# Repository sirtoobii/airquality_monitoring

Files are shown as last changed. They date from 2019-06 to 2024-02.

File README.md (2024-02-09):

### Air quality monitoring
This projects aims to create an air quality monitoring setup with inexpensive components. Initially
setup with an Arduino nano but later ported to a Raspberry PI.

The data is collected using the following sensors:  
- BMP180 (Air pressure, Temperature)
- MH-Z19B (Co2 concentration)
- SMT20 (Humidity, Temperature)
To interface with the sensors, either an Arduino or Raspberry PI computer can be used

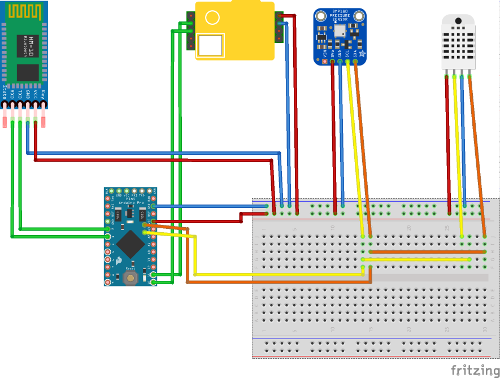
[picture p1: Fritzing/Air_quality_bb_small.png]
Ardunio board


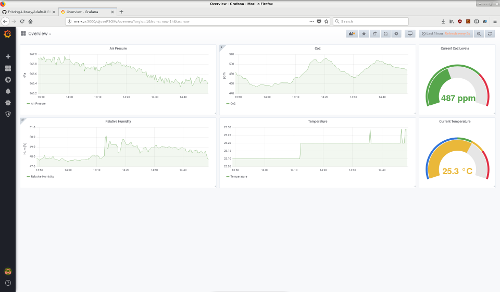
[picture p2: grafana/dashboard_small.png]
Grafana Dashboard


### Project Structure

| Folder | Description | Remarks |
|---|---|---|
| `Fritzing` | The Fritzing projcet | Get fritzing here:[https://fritzing.org/home/](https://fritzing.org) |
| `additional` | Datasets for the sensors | |
| `arduino` | Ardunio libraries and source code. | This is a platfrom-io project. More info [https://platformio.org/](here) |
| `grafana` | Just the exported `grafana` dashboard | |
| `pi` | This project implemented on a Raspberry PI | |
| `python` | Python files: Write data values to the influx db (`data_logger.py`) and scan for new advertisement packets (`scanner.py`) |  There is `requirements.txt` file present, which use to install all required packages: ```pip install -i requirements.txt``` |

### Technology Stack
- Data is stored in a Influx-DB
- A Grafana-Dashboard is used to display the measured values
- Scripting language at the receiver-side is Python `3.6`
- (Arduino) The data is transmitted using iBeacon `UUID-String` (yes this is a hack see more info below)

### Data transmission (Arduino)
As mentioned above the collected data is transmitted using Bluetooth Low Energy to
the receiver. Generally speaking, the data is transmitted using the advertisement
data:
```
Index         :        7   11 13   15     19 21   23 25                  39
                       |    |  |    |      |  |    |  |                   |
Example string: 4c000215 0190 1b   27   03c9 27   a0 a0   0000000 000000 2d       ffe0ffe1 c5
Labels        : Ibeacon  co2  temp.temp pres.pres hum.hum ------- ------ checksum other_stuff
```
However, since the HM-10 does not support changing the advertisement data
directly, I had to _abuse_ the iBeacon mode where you can change 32 Bytes of the `UUID-String`. To make things worse (more interesting!), the BLE-Module only allows you to
change 8 Bytes of the `UUID-String` at once. For example the `AT` command for the first 8 Bytes:
```
AT+IBE0AABBCCDD # As a side-note: all Hex-Characters have to be upper-case
```
And you guessed it, you can't control **when** an advertisement package is sent.
This the reason the checksum is needed :)

### Future work, remarks and problems
- Currently only one temperature value is evaluated. However, all sensors measure
temperature, therefore we could compare them and even create some sort of a _confidence-interval_
- If you power on the whole circuit, the first _valid_ (according to the checksum) transmitted value of the co2-sensor is sometimes way off (in the 5-6k area)
- Don't buy the components on aliexpres or similar. I've wasted (too) many hours figuring out that for example the HM-10 Module was a clone of a _clone_ of the original.
- Feedback, ideas and PR's welcome :)

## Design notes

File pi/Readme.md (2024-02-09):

# Raspberry PI variant

The same project but implemented on a Raspberry PI instead of an Arduino. 

## Raspberry PI setup

- Enable I2C: `raspi-config->Interface Options->I2C`
- Enable Serial port: `raspi-config->Interface Options->Serial Port` (login shell: no) (serial port hardware: yes)
- Wiring: Check comments in each sensor implementation
- 
Setup Python3 environment (inside `/pi` directory)

```shell
# Setup venv
python3 -m venv venv

# activate venv
source venv/bin/activate

# install requirements
pip install -r requirements.txt

# copy and edit .env file according your local environment
cp .env.dist .env

# add your user to "dialout" group to access the serial and i2c interface as non root user
usermod -aG dialout <user_name>
```
The corresponding systemd service (to be placed in `/usr/lib/systemd/system/raspi-airquality.service`)
```text
[Unit]
Description=Air-quality Monitoring
After=network.target
Wants=network-online.target

[Service]
Restart=always
Type=simple
Type=simple
ExecStart=/home/<user_name>/airquality_monitoring/pi/venv/bin/python3 /home/<user_name>/airquality_monitoring/pi/app/main.py
User=<user_name>
Group=<user_group>

[Install]
WantedBy=multi-user.target 
```

You probably also want to enable the service on boot: `systemctl enable raspi-airquality.service`

## Influx and Grafana

I highly recommend using this docker-compose setup: [https://github.com/sirtoobii/docker-compose-influxdb-grafana](https://github.com/sirtoobii/docker-compose-influxdb-grafana). The [included grafana
dashboard config](../grafana/Dashboard_config_influx_2_0.json) should work right away with this setup.

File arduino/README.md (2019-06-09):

### arduino_airquality
This project is work in progress!

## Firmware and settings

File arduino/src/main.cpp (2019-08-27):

#include <Wire.h>
#include <Adafruit_Sensor.h>
#include <Adafruit_BMP085_U.h>
#include <SoftwareSerial.h>
#include <DFRobot_SHT20.h>

#define unsigned char byte
#define CLOCK 20000 //Internal clock rate in milliseconds

/**
 * Common pitfalls:
 * - Allways clear serial buffers!
 * - When defining multiple SoftwareSerial objects make sure to call serial_object.listen() before interacting!
 */

SoftwareSerial SerialBLE(2, 3);  // BLE
SoftwareSerial SerialCO2(10,11);  // CO2
Adafruit_BMP085_Unified bmp = Adafruit_BMP085_Unified(10085); //Temperature & Presure
DFRobot_SHT20 sht20; //Humitity



byte READ_CO2[]={0xff,0x01,0x86,0x00,0x00,0x00,0x00,0x00,0x79};  //Befehl zum Auslesen der CO2 Konzentration

static char globalErrorState = 0x0;
const static char HEX_C[17]="0123456789ABCDEF";

/*
 * Possibile Error states
 * 0x0: No error
 * 0x1: Error at init BMP085
 * 0x2: Error at init SHT20
 * 0x3: Error reading sensor BMP085
 * 0x5: Error converting the data
 */
void indicateError(bool blocking=false){
  if (globalErrorState != 0x0) {
    while(true){
    for (int i=0; i<globalErrorState; i++){
        digitalWrite(LED_BUILTIN, HIGH);
        delay(100);
        digitalWrite(LED_BUILTIN, LOW);
        delay(100);
      }
      if (!blocking) {
        break;
      }
      delay(1000);
    }
    }
}
/**
 * Takes a char array a fills it with a given character
 **/
void fillWithChar(char data[], char character, int data_size){
  for (int i = 0; i < data_size; i++){
    data[i] = character;
  }
}

/**
 * Just writes an input char array to the BLE module. Also prints the response
 * to UART.
 **/
void writeToBle(const char * data){
  SerialBLE.listen();
  while (SerialBLE.available() >0) {     //Hier wird der Buffer der Seriellen Schnittstelle gelehrt
    SerialBLE.read();
  }
  Serial.println(data);
  SerialBLE.write(data);
  Serial.println(SerialBLE.readString());
}

/**
 * Converts an integer to its HEX representation and packs it into an char
 * array of a given length. The unused space in the array is padded with '0'.
 *
 **/
void packIntoHexChar(char data[], int buf_size, int value){
  static char hb = 0x0;
  static char lb = 0x0;
  static char int_chars[5] = "0000";
  //Fill with zero characters
  for (int i = 0; i<buf_size -1; i++){
    data[i] = '0';
  }
  //Convert value to hex
  hb = highByte(value);
  lb = lowByte(value);
  int_chars[0] = HEX_C[hb>>4 & 0x0F];
  int_chars[1] = HEX_C[hb & 0x0F];
  int_chars[2]=  HEX_C[lb>>4 & 0x0F];
  int_chars[3] = HEX_C[lb & 0x0F];
  //set value
  for (int i = buf_size -2; i >= 0; i--){
    if (buf_size -i <=5 ){
      data[i] = int_chars[(i+1) - (buf_size - 4)];
    }
  }
}
/**
 * Implemention of the "Fletcher's Checksum". To fit the result into two
 * HEX character we READ_CO2pute the modulo 16 of each value.
 **/
int sum1 = 0;
int sum2 = 0;
void computeChecksum(char input[], int input_size, char output[]){
  sum1 = 0;
  sum2 = 0;
  for (int i = 0; i < input_size; i++) {
    sum1 = (sum1 + input[i]) % 255;
    sum2 = (sum2 + sum1) % 255;
  }

output[0] = HEX_C[lowByte(sum1 % 16) & 0x0F];
output[1] = HEX_C[lowByte(sum2 % 16) & 0x0F];
}

/**
 * Takes an float value and converts it to a hex representation:
 * 16.16 => 000F000F (if the size is set to 5 (4))
 **/
void float2Hex(float value, double precision, char whole[], int whole_size, char remainder[], int remainder_size){
  static int v_whole = 0;
  static int v_remainder = 0;
  v_whole = value;
  v_remainder = (value - v_whole) * (int) pow(10, precision);
  packIntoHexChar(whole, whole_size, v_whole);
  packIntoHexChar(remainder, remainder_size, v_remainder);
}

/**
 * Takes an char array with a maximum length of 32 and distributes its contents
 * over the UUID field of the BLE module.
 */



void writeToUUID(char data[], int data_size){
  static char _data[9] = "00000000";
  static char _toSend[17];
  static char _READ_CO2mand[8];
  static char _checksum[3] = "00";
  static int array_pointer = 0;
  static int n_registers = 0;
  static int tail = 0;
  //Determine how many registers we need
  n_registers = data_size / 8;
  tail = data_size % 8;
  //Set checksum
  computeChecksum(data, data_size, _checksum);
  if (data_size > 30) {
    Serial.println("Too much data for the uuid field. 30 Bytes max! (last two are the checksum)");
    return;
  }
  //Easy base case
  if (n_registers == 0 && tail > 0){
    fillWithChar(_data, '0', 8);
    for (int i = 0; i < 8; i++){
      _data[i] = data[i];
    }
    strcpy(_toSend, "AT+IBE0");
    strcat(_toSend, _data);
    writeToBle(_toSend);
    return;
  }
  array_pointer = 0;
  //Process all except tail
  for (int i = 0; i< n_registers; i++){
    fillWithChar(_data, '0', 8);
    for (int j = array_pointer; j < 8 + array_pointer; j++){
      _data[j - array_pointer] = data[j];
    }
    array_pointer += 8;
    //Only send if this is not the last register
    if (i < 3){
      sprintf(_READ_CO2mand, "AT+IBE%d", i);
      strcpy(_toSend, _READ_CO2mand);
      strcat(_toSend, _data);
      writeToBle(_toSend);
    }
  }
  //Process tail
  if (array_pointer < data_size ) {
    fillWithChar(_data, '0', 8);
    for (int i = 0; i < data_size - array_pointer ; i++){
      _data[i] = data[i+array_pointer];
    }
    //Only send if this is not the last register
    if (n_registers < 3){
      sprintf(_READ_CO2mand, "AT+IBE%d", n_registers);
      strcpy(_toSend, _READ_CO2mand);
      strcat(_toSend, _data);
      writeToBle(_toSend);
    }
  }
  if (n_registers < 3){
    fillWithChar(_data, '0', 8);
  }
  //Write last register with checksum
  sprintf(_READ_CO2mand, "AT+IBE%d", 3);
  _data[6] = _checksum[0];
  _data[7] = _checksum[1];
  strcpy(_toSend, _READ_CO2mand);
  strcat(_toSend, _data);
  writeToBle(_toSend);
}

void setup(void)
{
  // Setupo led
  pinMode(LED_BUILTIN, OUTPUT);

  //Setup main serial
  Serial.begin(9600);
  Serial.println("Starting module");

  //Co2 Serial
  SerialCO2.begin(9600);  //Initialisierung der seriellen Schnittstelle für den ersten Sensor

  //Setup ble serial
  SerialBLE.begin(9600); // Sometimes the default baud rate is also 115200
  writeToBle("AT"); // Wake up
  writeToBle("AT+NAMEsensortag1"); //Set name
  writeToBle("AT+ADVIA"); // Set Advertising rate to  2000ms
  writeToBle("AT+ADTY3"); // Only advertise, no connect
  writeToBle("AT+IBEA1"); // Enable iBeacon mode
  //Reset id (we somehow can't set them to 0x0)
  writeToBle("AT+IBE000000001");
  writeToBle("AT+IBE100000001");
  writeToBle("AT+IBE200000001");
  writeToBle("AT+IBE300000001");
  writeToBle("AT+PWRM1"); // Disable sleep mode since I found no (working) way to enter operation mode again
  writeToBle("AT+RESET"); // Restart
  delay(1000);
  writeToBle("AT");

  Serial.println("Module is ready, initializing sensors...");
  //Indicate BLE ready
  digitalWrite(LED_BUILTIN, HIGH);
  delay(100);
  digitalWrite(LED_BUILTIN, LOW);
  delay(100);
  digitalWrite(LED_BUILTIN, HIGH);
  delay(100);
  digitalWrite(LED_BUILTIN, LOW);
  delay(100);

  // Setup BMP085
  if(!bmp.begin())
  {
    Serial.print("Ooops, no BMP085 detected");
    globalErrorState = 0x1;
    indicateError(true);
  }
  sht20.initSHT20();
  delay(100);

  Serial.println("Sensors initialized successfully");
}

void loop(void){
  static float temp = 0.0;
  static float presure = 0.0;
  static int co2_concentration = 0;
  static float humidity = 0.0;

  //co2 read buffer
  static byte buf_read_co2[9];

  //Send buffers
  static char buf_co2[5] = "0000";
  static char buf_temp_whole[3] = "00";
  static char buf_temp_remainder[3] = "00";
  static char buf_pres_whole[5] = "0000";
  static char buf_pres_remainder[3] = "00";
  static char buf_hum_whole[3] = "00";
  static char buf_hum_remainder[3] = "00";

  //Prepare whole buffer (only 19 since 25 - 6)
  // -6 Because we can remove the string termination characters
  static char buf_toSend[19];


  // Get a new sensor event
  sensors_event_t event;
  bmp.getEvent(&event);

  if (event.pressure)
  {
    presure = event.pressure;
    bmp.getTemperature(&temp);
    globalErrorState = 0x0;
  }
  else
  {
    globalErrorState = 0x3;
  }

  //Read co2 readings
  SerialCO2.listen();
  //Flush buffer
  while (SerialCO2.available() >0) {
    SerialCO2.read();
  }
  SerialCO2.write(READ_CO2,9);
  SerialCO2.readBytes(buf_read_co2,9);
  Serial.println(buf_read_co2[2]);
  co2_concentration = buf_read_co2[2]*256+buf_read_co2[3];


  // Read humidity
  humidity = sht20.readHumidity();


  indicateError();
  Serial.println(co2_concentration);
  fillWithChar(buf_co2, '0', 4);
  packIntoHexChar(buf_co2, 5, co2_concentration);

  Serial.println(temp);
  fillWithChar(buf_temp_whole, '0', 2);
  fillWithChar(buf_temp_remainder, '0', 2);
  float2Hex(temp, 2.0, buf_temp_whole, 3, buf_temp_remainder, 3);

  Serial.println(presure);
  fillWithChar(buf_pres_whole, '0', 4);
  fillWithChar(buf_pres_remainder, '0', 2);
  float2Hex(presure, 2.0, buf_pres_whole, 5, buf_pres_remainder, 3);

  Serial.println(humidity);
  fillWithChar(buf_hum_whole, '0', 2);
  fillWithChar(buf_hum_remainder, '0', 2);
  float2Hex(humidity, 2.0, buf_hum_whole, 3, buf_hum_remainder, 3);

  strcpy(buf_toSend, buf_co2);
  strcat(buf_toSend, buf_temp_whole);
  strcat(buf_toSend, buf_temp_remainder);
  strcat(buf_toSend, buf_pres_whole);
  strcat(buf_toSend, buf_pres_remainder);
  strcat(buf_toSend, buf_hum_whole);
  strcat(buf_toSend, buf_hum_remainder);

  //Set UUID (only 18 since we don't need the termination character)
  writeToUUID(buf_toSend, 18);

  digitalWrite(LED_BUILTIN, HIGH);
  delay(100);
  digitalWrite(LED_BUILTIN, LOW);
  delay(100);
  digitalWrite(LED_BUILTIN, HIGH);
  delay(100);
  digitalWrite(LED_BUILTIN, LOW);
  delay(100);
  delay(CLOCK);
}

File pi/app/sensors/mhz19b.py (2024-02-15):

import time
import serial


class MHZ19B:
    """
    Interface the MHZ19B Co2 sensor.

    GPIO connections:
    - 2: VIN 5V
    - 6: GND
    - 8 (GPIO 14, TXD): RX
    - 10 (GPIO 15, RXD): TX

    """

    def __init__(self, serial_device: str):
        self.serial_device = serial_device

    def _send_serial_command(self, cmd: bytes, n_resp_bytes: int = 0):
        handle = serial.Serial(self.serial_device, baudrate=9600, timeout=1.0, bytesize=serial.EIGHTBITS,
                               parity=serial.PARITY_NONE, stopbits=serial.STOPBITS_ONE)
        time.sleep(0.01)
        try:
            handle.write(cmd)
            time.sleep(0.01)
            if n_resp_bytes > 0:
                _resp = handle.read(9)
                if len(_resp) > 0:
                    # We do not check the checksum because after ~24h of continuous operation, the checksum is always incorrect.
                    return _resp
                else:
                    raise IOError("MHZ19B: No data read")
        finally:
            handle.close()

    def read_co2_concentration(self):
        cmd = bytearray([0xFF, 0x01, 0x86, 0x00, 0x00, 0x00, 0x00, 0x00, 0x79])
        _resp = self._send_serial_command(cmd, 9)
        if _resp is not None:
            return _resp[2] * 256 + _resp[3]

    def zero_point_calibration(self):
        cmd = bytearray([0xFF, 0x01, 0x87, 0x00, 0x00, 0x00, 0x00, 0x00, 0x78])
        self._send_serial_command(cmd)

    @staticmethod
    def checksum(data: bytes):
        _sum = 0
        for byte in data[1:]:
            _sum += byte
        _sum = 0xFF - _sum
        return (_sum + 1) & 0xFF


if __name__ == '__main__':
    z = MHZ19B(serial_device="/dev/serial0")
    print(z.read_co2_concentration())

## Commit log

2019-06-30 Hopefully fixed memory leak(s).
    [main.cpp]
2019-08-01 Added proper project description
    [Air_quality.fzz]
2019-08-27 added sample rate limit, added co2 upperbound
2024-02-09 Added raspberry pi variant
